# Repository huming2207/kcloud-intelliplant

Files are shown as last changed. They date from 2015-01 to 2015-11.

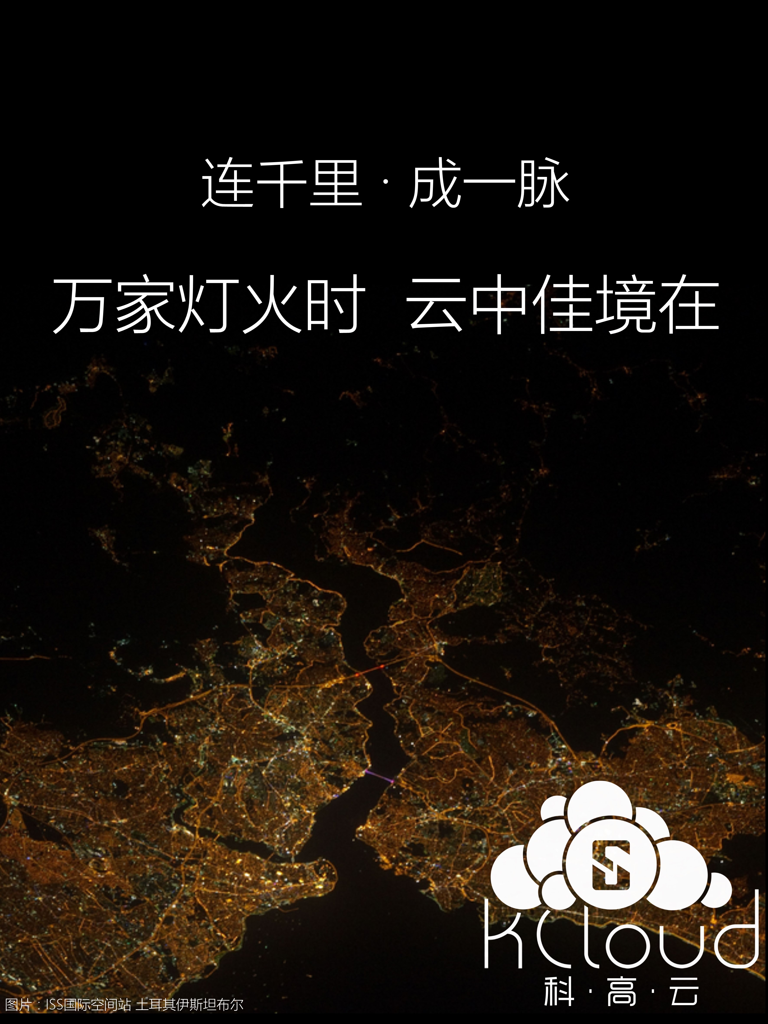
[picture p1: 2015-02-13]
RaspiController/PC Client/KCloud IntelliPlant for Windows/Resources/3月海报2.jpg

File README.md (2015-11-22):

# HuStudio IntelliPlant
One of the sub-projects of Shenzhen Highschool of Science former "KCloud" private cloud service project.

=========
Overview
=========
The IntelliPlant project is one of the sub-projects of Shenzhen High School of Science KCloud. 

It's an Arduino based open source crop auto-managing system.

The project mainly maintained by Jackson Ming Hu in KGTCU, Techonology Clubs Union of Shenzhen High School of Science.

It has two parts, one is the master (controller) side, the other is slave (arduino nodes) side. The node is an Arduino Uno/ProMini/Mega or Raspberry Pi.

The node has a temperature & humidity sensor , an air pressure sensor and an air quality sensor and it controls the pump with a relay and it will automatically calculate the water capacity by the weather condition.

The controller can get the node's data by wireless UART serial port and then display the data on its screen and upload the data to Yeelink Cloud Platform.

=========
Development Environment Requirements 
=========

1. The PC client must use Virtual Studio version newer than 2012 or 2013, otherwise it will reports many strange mistakes.

2. Recommended development environment:

		--> Arduino IDE 1.60 for arduino node
		
		--> Virtual Studio 2013r3
		
		--> Debian 7.x or OpenWrt 14.04 "Barrier Breaker" for Raspberry Pi with Python 2.7   

=========
About this project
=========

Project author: IT Club, Technical Club Union of Shenzhen Highschool of Science

Project administrator: Jackson Ming Hu <huming2207@gmail.com>

Arduino software development: Jackson Ming Hu

PC Client development & advising: Jackson Ming Hu, Junhao Liang

Shield design: Yichuan Lee

This project is a open source project and all the source code are protected by GPLv2 licence.

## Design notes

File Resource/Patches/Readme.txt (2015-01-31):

HardwareSerial.cpp:

The arduino original hardware serial library's transfer buffer is too small, so I've changed the SERIAL_BUFFER_SIZE (originally definition is 64 bit) to 256bit for ATMEGA8U2/ATMEGA*28P/ATMEGA16U2 and 512bit for Atmega 2560 in case  of the data loss.

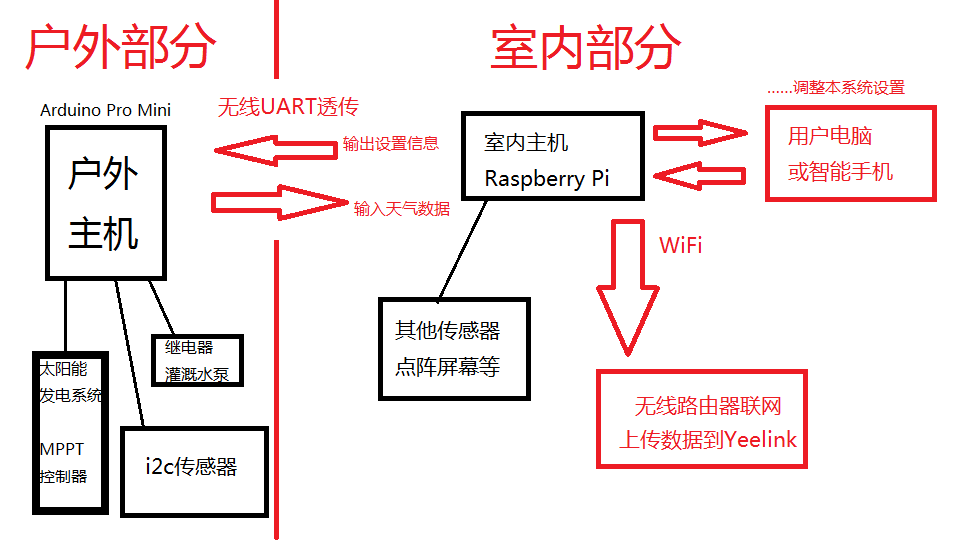
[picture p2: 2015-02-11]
Resource/mind-map-1.png

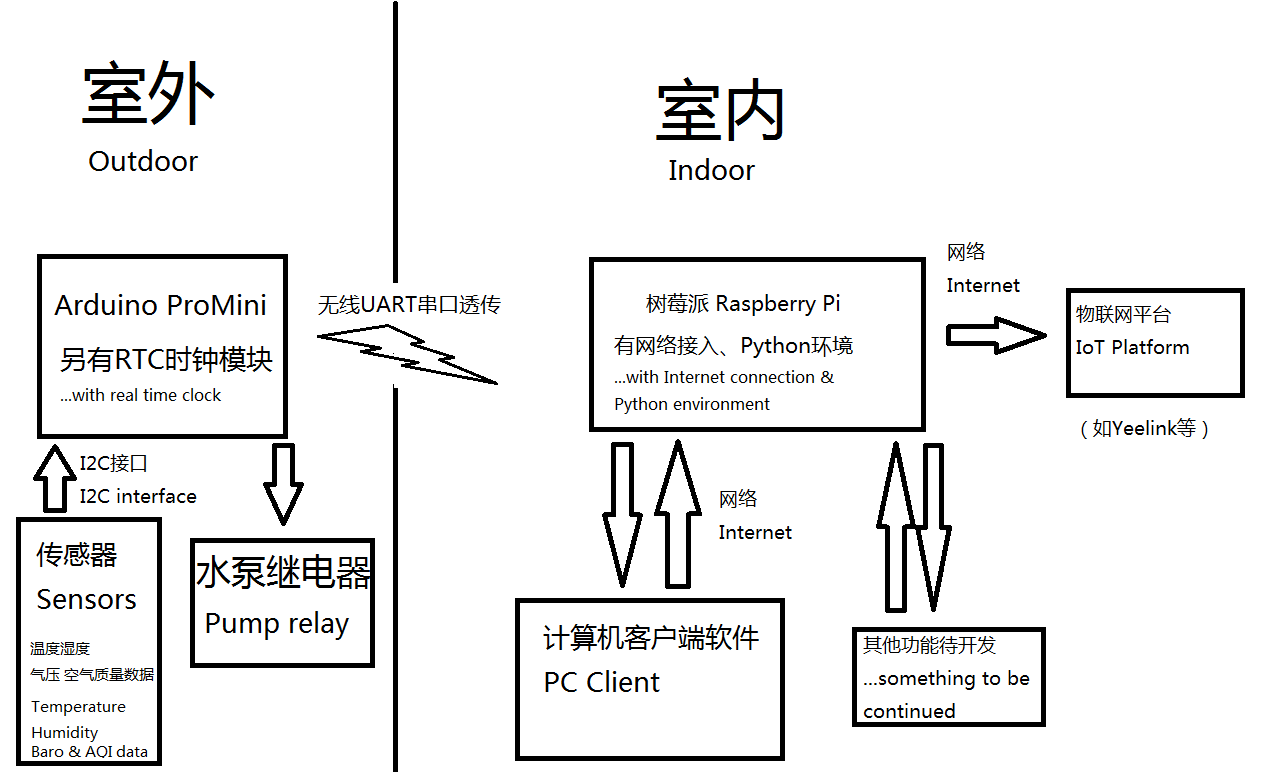
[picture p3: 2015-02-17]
Resource/mind-map-final.png

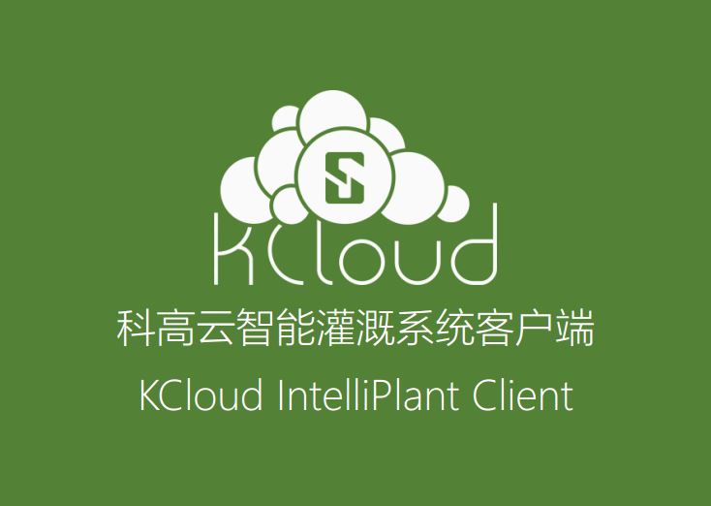
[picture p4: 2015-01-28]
Resource/mainstart.JPG

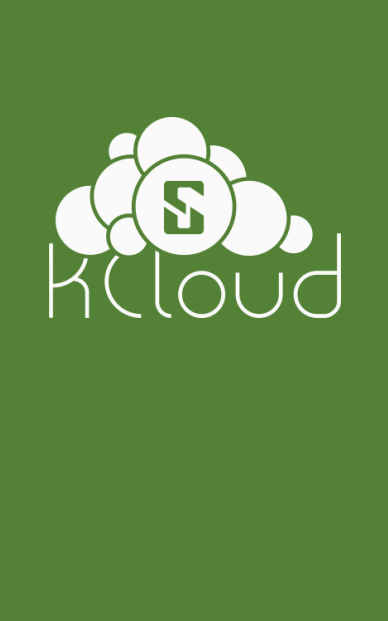
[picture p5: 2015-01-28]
Resource/about.PNG

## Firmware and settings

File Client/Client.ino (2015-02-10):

#include <Wire.h>
#include <LiquidCrystal_I2C.h>
#include <uartWIFI.h>
#include <avr/eeprom.h>
#define EEPROM_write(address, var) eeprom_write_block((const void *)&(var), (void *)(address), sizeof(var))
#define EEPROM_read(address, var) eeprom_read_block((void *)&(var), (const void *)(address), sizeof(var)) 

String WifiSSID;                
String WifiPassword;    
String SerialIn;
String YeelinkID1;
String YeelinkSensor1;
String YeelinkSensor2;
String YeelinkSensor3;
String YeelinkSensor4;
String YeelinkSensor5;
String YeelinkDeviceID;
float SerialNumData[9] = {0};

unsigned long lastConnectionTime = 0;          // last time you connected to the server, in milliseconds
boolean lastConnected = false;                 // state of the connection last time through the main loop
const unsigned long postingInterval = 5*1000; 
String returnValue = ""; 
boolean ResponseBegin = false;

/* Wifi Status. 
*/
int WifiStatus = 0;

LiquidCrystal_I2C lcd(0x27,20,4);  
WIFI wifi;
char YeelinkServer[] = "api.yeelink.net";


void setup()
{
  lcd.init();                      // Initialize the lcd 
  lcd.init();
  lcd.backlight();
  EEPROM_read(1000,WifiSSID);   // Read the Wifi SSID
  EEPROM_read(1500,WifiPassword); // Read the Wifi Password
  EEPROM_read(2000,YeelinkID1);
  EEPROM_read(300,YeelinkSensor1);
  EEPROM_read(400,YeelinkSensor2);
  EEPROM_read(500,YeelinkSensor3);
  EEPROM_read(600,YeelinkSensor4);
  EEPROM_read(700,YeelinkSensor5);
  EEPROM_read(800,YeelinkDeviceID);
  DebugSerial.println("SHSS KGTCU IntelliPlant Client");
  DebugSerial.println("Now initalized.");
  wifi.begin();
  bool b = wifi.Initialize(STA, WifiSSID, WifiPassword);
  if(!b)
  {
    DebugSerial.println("...Wifi hasn't connected successfully.");
      lcd.clear();
      lcd.setCursor(3,0);
      lcd.print("Hello, world!");
      lcd.setCursor(1,1);
      lcd.print("KCloud IntelliPlant");
      lcd.setCursor(0,2);
      lcd.print("WIFI CONNECTION FAIL");
      delay(10000);
      WifiStatus = -1;
  }
  delay(10000);
  lcd.setCursor(3,0);
  lcd.print("Hello, world!");
  lcd.setCursor(2,1);
  lcd.print("KCloud IntelliPlant");
  lcd.setCursor(0,2);
  lcd.print("IP:");
  lcd.print(wifi.showIP());
  lcd.setCursor(3,3);
  lcd.print("WIFI CONNECTED!!");
  delay(5000);
  WifiStatus = 1;
}


void loop()
{
    int j = 0;
    while (Serial.available() > 0)  
    {
        SerialIn += char(Serial.read());
        delay(2);
    }
    if (SerialIn.length() > 0)
    {
      if(SerialIn[0] == 'Y' || SerialIn[0] == 'F' || SerialIn[0] == 'A' || SerialIn[0] == 'B' || SerialIn[0] == 'C' || SerialIn[0] == 'D' || SerialIn[0] == 'E' || SerialIn[0] == 'W' ||  SerialIn[0] == 'R')
      {
       YeelinkDeviceIDSave();
       YeelinkIDSave();
       YeelinkSensorSave1();
       YeelinkSensorSave2();
       YeelinkSensorSave3();
       YeelinkSensorSave4();
       YeelinkSensorSave5();
       WifiPasswordSave();
       WifiSSIDSave();
      }
      else
      {
          for(unsigned int i = 0; i < SerialIn.length() ; i++)
          {
            if(SerialIn[i] == ',')
            {
               j++; //If meets a comma then j+1 and jump to the next setting data.
            }
            else
            {
               SerialNumData[j] = SerialNumData[j] * 10 + (SerialIn[i] - '0');
            }
          }

        SerialIn = String("");  // Clear up all the old SerialIn data.
        /* *******************************************************************************
           The "SerialNumData[0]" lets the server decide which setting should be changed. 
           1 = Normal weather data.
           2 = Schedule data.
          ******************************************************************************** */ 
        switch (int(SerialNumData[0])) {  
        case 1:
          YeeLinkSendSensorData();
          break;
        case 2:
          LCDShowSchedule();
          break;
        default: 
          break;
        }
        
        for(int i = 0; i < 10; i++)
        {
   	    SerialNumData[i] = 0;
        }
      }
    }
    LCDClearWithoutBlink();
    lcd.setCursor(3,0);
    lcd.print("Status:");
    switch (WifiStatus){
    case -1:
      lcd.print("NO WIFI");
      break;
    case 0:
      lcd.print("UNKNOWN");
      break;
    case 1:
      lcd.print("CONNECTED");
      break;
    case 2:
      lcd.print("NO INTERNET");
      break;
    default:
      break;
    }
    

    

}

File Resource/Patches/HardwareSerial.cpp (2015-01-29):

/*
  HardwareSerial.cpp - Hardware serial library for Wiring
  Copyright (c) 2006 Nicholas Zambetti.  All right reserved.

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
  Modified 23 November 2006 by David A. Mellis
  Modified 28 September 2010 by Mark Sproul
  Modified 14 August 2012 by Alarus
*/

#include <stdlib.h>
#include <stdio.h>
#include <string.h>
#include <inttypes.h>
#include "Arduino.h"
#include "wiring_private.h"

// this next line disables the entire HardwareSerial.cpp, 
// this is so I can support Attiny series and any other chip without a uart
#if defined(UBRRH) || defined(UBRR0H) || defined(UBRR1H) || defined(UBRR2H) || defined(UBRR3H)

#include "HardwareSerial.h"

/*
 * on ATmega8, the uart and its bits are not numbered, so there is no "TXC0"
 * definition.
 */
#if !defined(TXC0)
#if defined(TXC)
#define TXC0 TXC
#elif defined(TXC1)
// Some devices have uart1 but no uart0
#define TXC0 TXC1
#else
#error TXC0 not definable in HardwareSerial.h
#endif
#endif

// Define constants and variables for buffering incoming serial data.  We're
// using a ring buffer (I think), in which head is the index of the location
// to which to write the next incoming character and tail is the index of the
// location from which to read.
#if (RAMEND <= 1000)
	 #define SERIAL_BUFFER_SIZE 64
#else
#if (RAMEND <= 2000)
	 #define SERIAL_BUFFER_SIZE 256
#else
	 #define SERIAL_BUFFER_SIZE 512
#endif
#endif

struct ring_buffer
{
  unsigned char buffer[SERIAL_BUFFER_SIZE];
  volatile unsigned int head;
  volatile unsigned int tail;
};

#if defined(USBCON)
  ring_buffer rx_buffer = { { 0 }, 0, 0};
  ring_buffer tx_buffer = { { 0 }, 0, 0};
#endif
#if defined(UBRRH) || defined(UBRR0H)
  ring_buffer rx_buffer  =  { { 0 }, 0, 0 };
  ring_buffer tx_buffer  =  { { 0 }, 0, 0 };
#endif
#if defined(UBRR1H)
  ring_buffer rx_buffer1  =  { { 0 }, 0, 0 };
  ring_buffer tx_buffer1  =  { { 0 }, 0, 0 };
#endif
#if defined(UBRR2H)
  ring_buffer rx_buffer2  =  { { 0 }, 0, 0 };
  ring_buffer tx_buffer2  =  { { 0 }, 0, 0 };
#endif
#if defined(UBRR3H)
  ring_buffer rx_buffer3  =  { { 0 }, 0, 0 };
  ring_buffer tx_buffer3  =  { { 0 }, 0, 0 };
#endif

inline void store_char(unsigned char c, ring_buffer *buffer)
{
  int i = (unsigned int)(buffer->head + 1) % SERIAL_BUFFER_SIZE;

  // if we should be storing the received character into the location
  // just before the tail (meaning that the head would advance to the
  // current location of the tail), we're about to overflow the buffer
  // and so we don't write the character or advance the head.
  if (i != buffer->tail) {
    buffer->buffer[buffer->head] = c;
    buffer->head = i;
  }
}

#if !defined(USART0_RX_vect) && defined(USART1_RX_vect)
// do nothing - on the 32u4 the first USART is USART1
#else
#if !defined(USART_RX_vect) && !defined(USART0_RX_vect) && \
    !defined(USART_RXC_vect)
  #error "Don't know what the Data Received vector is called for the first UART"
#else
  void serialEvent() __attribute__((weak));
  void serialEvent() {}
  #define serialEvent_implemented
#if defined(USART_RX_vect)
  ISR(USART_RX_vect)
#elif defined(USART0_RX_vect)
  ISR(USART0_RX_vect)
#elif defined(USART_RXC_vect)
  ISR(USART_RXC_vect) // ATmega8
#endif
  {
  #if defined(UDR0)
    if (bit_is_clear(UCSR0A, UPE0)) {
      unsigned char c = UDR0;
      store_char(c, &rx_buffer);
    } else {
      unsigned char c = UDR0;
    };
  #elif defined(UDR)
    if (bit_is_clear(UCSRA, PE)) {
      unsigned char c = UDR;
      store_char(c, &rx_buffer);
    } else {
      unsigned char c = UDR;
    };
  #else
    #error UDR not defined
  #endif
  }
#endif
#endif

#if defined(USART1_RX_vect)
  void serialEvent1() __attribute__((weak));
  void serialEvent1() {}
  #define serialEvent1_implemented
  ISR(USART1_RX_vect)
  {
    if (bit_is_clear(UCSR1A, UPE1)) {
      unsigned char c = UDR1;
      store_char(c, &rx_buffer1);
    } else {
      unsigned char c = UDR1;
    };
  }
#endif

#if defined(USART2_RX_vect) && defined(UDR2)
  void serialEvent2() __attribute__((weak));
  void serialEvent2() {}
  #define serialEvent2_implemented
  ISR(USART2_RX_vect)
  {
    if (bit_is_clear(UCSR2A, UPE2)) {
      unsigned char c = UDR2;
      store_char(c, &rx_buffer2);
    } else {
      unsigned char c = UDR2;
    };
  }
#endif

#if defined(USART3_RX_vect) && defined(UDR3)
  void serialEvent3() __attribute__((weak));
  void serialEvent3() {}
  #define serialEvent3_implemented
  ISR(USART3_RX_vect)
  {
    if (bit_is_clear(UCSR3A, UPE3)) {
      unsigned char c = UDR3;
      store_char(c, &rx_buffer3);
    } else {
      unsigned char c = UDR3;
    };
  }
#endif

void serialEventRun(void)
{
#ifdef serialEvent_implemented
  if (Serial.available()) serialEvent();
#endif
#ifdef serialEvent1_implemented
  if (Serial1.available()) serialEvent1();
#endif
#ifdef serialEvent2_implemented
  if (Serial2.available()) serialEvent2();
#endif
#ifdef serialEvent3_implemented
  if (Serial3.available()) serialEvent3();
#endif
}
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

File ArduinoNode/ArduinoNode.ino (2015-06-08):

#include <AM2321.h>
#include <EEPROM.h>
#include <Wire.h>
#include <DS3231RTC.h>



 /* BMP180/BMP085 barometer statements and settings */
#define BMP085_ADDRESS 0x77 
float temperature;
float pressure;

const unsigned char OSS = 0; 
int ac1;
int ac2;
int ac3;
unsigned int ac4;
unsigned int ac5;
unsigned int ac6;
int b1;
int b2;
int mb;
int mc;
int md;
long b5; 

/* Dallas (Maxim) DS3231 RTC Clock statements and settings */
DS3231RTC RTC;
Time t;

/* DHT33 (aka. AM232x) statements */
AM2321 DHT;

/* MQ135 toxic gas sensor */
float GasPPM;
float GasAlg;

/* Serial input statements */
String SerialIn;
float SerialNumData[9] = {0};

/* Relay control pin on D7 */
int RelayControl = 8;

/* Declare some schedule integers */
int ScheduleHr;
int ScheduleMin;
int ScheduleSec;
unsigned long ScheduleCapacity;
int ScheduleStatus;
int ScheduleNum;
int Sec1;
int Min1;
int Hr1;
int Ratio;
long XWeatherOut;
unsigned long YWeatherOut;
int AutoSwitch;
int MainSwitch = 0;

/* SolarMonitor statements */
int SolarVoltageAnalog = 0; // The solar voltage analog data from Analog Pin 0 (A0)
int SolarCurrentAnalog = 1; // The solar current analog data from Analog Pin 1 (A1)
float SolarVoltage;
float SolarCurrent;


void setup(){
      digitalWrite(7, HIGH);
      pinMode(7, OUTPUT);
      Serial.begin(9600);
      pinMode(RelayControl,OUTPUT);
      digitalWrite(RelayControl,LOW);
      bmp085Calibration();
      t = RTC.getTime();
}




void loop(){
      GasAlg = float(analogRead(A3));
      GasPPM = (GasAlg / 1023.00) * float(InputVcc()) * 0.25;
      pressure = bmp085GetPressure(bmp085ReadUP());
       
        /* Simplify the code in main Server.ino */
       SerialDataRead();  // Read the serial data first. :-)
       SerialWeatherOutput();
        
        /* Check if the time meets the schedule */
       RelaySchedule1();
       RelaySchedule2();
       RelaySchedule3();
       
       SolarVoltageCalculate();
       SolarCurrentCalculate();
       
}

void BoardReset(){
  /* 
      Use a very short watchdog loop to force reset the arduino
      See also: http://www.atmel.com/images/Atmel-8271-8-bit-AVR-Microcontroller-ATmega48A-48PA-88A-88PA-168A-168PA-328-328P_datasheet_Complete.pdf
                http://playground.arduino.cc/Main/ArduinoReset
       But, unfortunately some Chinese Arduino ProMini clones (including mine)  have some issues on bootloader, so if we use the AVR internal watchdog, it would get stuck when reboot
       See also :http://arduino.stackexchange.com/questions/2922/watchdog-timer-stuck-in-restart-loop-green-led-flashing
       
  
  */
  
  /* 
      Here, we need to connect a wire between pin D7 and pin DTR (reset)
      According to my experiments, a pull-up resistor is unnecessary.
  */    
  digitalWrite(7, LOW);

}

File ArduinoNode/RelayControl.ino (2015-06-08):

/* 
    SHSS KCloud IntelliPlant Node source code
    Author: Jackson Ming Hu <huming2207@gmail.com>
            Technical Club Union of Shenzhen Highschool of Science
            ...and some unknown guys including the TAOBAO retailers, thanks them!!
			深圳科学高中 科高云子项目 智慧农业物联网灌溉机
			深圳科学高中技术类社团联合会自动化电子项目组
			程序作者：胡铭 huming2207@gmail.com
			
    ***THIS CODE IS PROTECTED BY LGPL LICENCE, FOR NON-COMMERCIAL USE ONLY! ***
        本程序受LGPL协议保护，严禁商用。
     
     RelayControl.ino -->   Relay timing controller 
                            
                       
*/

void CalculateWeather(){
  /* 
     This is a testing formula of the "Weather2WaterCapacity" part.
     It's too humble, but I will keep working on it. ----Jackson @ Jan 30 2015
     
     Some requirements:
     1. The pump must work longer than 10 seconds per schedule and less than 60 seconds per schedule.
     2. ... (To be continued. I will ask my mum and grandma some advices, who is expert in agriculture.)
   */
  DHT.read();
  Ratio = int(EEPROM.read(20));
  XWeatherOut = (int((DHT.humidity/2)) - int((DHT.temperature/1.5)) - int((pressure/5000)));
  YWeatherOut = -XWeatherOut + 60 + Ratio;
  if (YWeatherOut > 60){
    YWeatherOut = 60; // Force the output shorter than 60.
  }
  if (YWeatherOut < 10){
    YWeatherOut = 10; // Force the output longer than 60.
  }
}


/* 
     BEGIN PUMP RELAY SCHEDULE PARTS 
     
     Feb 11 2015: I have no choice but to use delay(), since it is the easiest and the most stable way to control the interruption of the pump without Time library.
     
*/

void RelaySchedule1(){
  t = RTC.getTime();
  ScheduleHr = int(EEPROM.read(1));
  ScheduleMin = int(EEPROM.read(2));
  ScheduleSec = int(EEPROM.read(3));
  ScheduleCapacity = int(EEPROM.read(4));
  MainSwitch = int(EEPROM.read(5));
  AutoSwitch = int(EEPROM.read(6));
  
  
  if (MainSwitch == 1 && ScheduleHr == t.hour() && ScheduleMin == t.minute() && ScheduleSec == t.second())
  {
    digitalWrite(RelayControl, HIGH);
    if (AutoSwitch == 1)
    {
        SerialScheduleOutput();
        delay(YWeatherOut * 1000L);
        digitalWrite(RelayControl,LOW);
        //BoardReset();
    }
    else
    {
        SerialScheduleOutput();
        delay(ScheduleCapacity * 1000L);
        digitalWrite(RelayControl,LOW);
        //BoardReset();
    }
  }
}


void RelaySchedule2(){
  t = RTC.getTime();
  ScheduleHr = int(EEPROM.read(7));
  ScheduleMin = int(EEPROM.read(8));
  ScheduleSec = int(EEPROM.read(9));
  ScheduleCapacity = int(EEPROM.read(10));
  MainSwitch = int(EEPROM.read(11));
  AutoSwitch = int(EEPROM.read(12));
  
  
  if (MainSwitch == 1 && ScheduleHr == t.hour() && ScheduleMin == t.minute() && ScheduleSec == t.second())
  {
    digitalWrite(RelayControl, HIGH);
    if (AutoSwitch == 1)
    {
        SerialScheduleOutput();
        delay(YWeatherOut * 1000L);
        digitalWrite(RelayControl,LOW);
        //BoardReset();
    }
    else
    {
        SerialScheduleOutput();
        delay(ScheduleCapacity * 1000L);
        digitalWrite(RelayControl,LOW);
        //BoardReset();
    }
  }
}

void RelaySchedule3(){
  t = RTC.getTime();
  ScheduleHr = int(EEPROM.read(13));
  ScheduleMin = int(EEPROM.read(14));
  ScheduleSec = int(EEPROM.read(15));
  ScheduleCapacity = int(EEPROM.read(16));
  MainSwitch = int(EEPROM.read(17));
  AutoSwitch = int(EEPROM.read(18));
  
  
  if (MainSwitch == 1 && ScheduleHr == t.hour() && ScheduleMin == t.minute() && ScheduleSec == t.second())
  {
    digitalWrite(RelayControl, HIGH);
    if (AutoSwitch == 1)
    {
        SerialScheduleOutput();
        delay(YWeatherOut * 1000L);
        digitalWrite(RelayControl,LOW);
        //BoardReset();
    }
    else
    {
        SerialScheduleOutput();
        delay(ScheduleCapacity * 1000);
        digitalWrite(RelayControl,LOW);
        //BoardReset();
    }
  }
}




void EEPROMDebug(){
  ScheduleHr = int(EEPROM.read(1));
  ScheduleMin = int(EEPROM.read(2));
  ScheduleSec = int(EEPROM.read(3));
  ScheduleCapacity = int(EEPROM.read(4));
  MainSwitch = int(EEPROM.read(5));
  AutoSwitch = int(EEPROM.read(6));
  Serial.println("** DEBUG: EEPROM - SCHEDULE");
  Serial.print("** ");
  Serial.print(ScheduleHr);
  Serial.print("  ");
  Serial.print(ScheduleMin);
  Serial.print("  ");
  Serial.print(ScheduleSec);
  Serial.print("  ");
  Serial.print(ScheduleCapacity);
  Serial.print("  ");
  Serial.println(MainSwitch);
}  

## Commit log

2015-01-28 Redesigned a new type of serial protocol
    Redesigned a new type of serial protocol between server and client.
    [Settings.ino]
2015-01-28 Add 3rd library -- IIC LCD Control
    [diff.txt]
2015-01-28 Add saving settings section for Client & fix bugs
    Add saving settings section for Client & fix bugs
    [Client.ino, Settings.ino]
2015-01-28 Update UI design for PC client
    Just a UI design, I'm still working for the arduino.
2015-01-29 Add arduino HardwareSerial patch
2015-01-29 Found a small mistake
    [Client.ino]
2015-01-31 修正一些意识形态问题
2015-02-01 Several changes to Server
    1. Change the AM2301 (DHT21) sensor to AM2321, since it is not stable
    and often cause strange crashes.
    2. Remove adafruit BOSCH barometer library and ported the MMWCGND BOSCH
    barometer library to optmize and reduce the whole firmware's size.
    [Barometer.ino, RelayControl.ino, SerialOutput.ino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]
2015-02-04 Update Server and PC client software
    My AM2321 (aka. DHT3x) has arrived and now all the staffs restarted. I
    hope I can finish them before Chinese Spring festival~!
2015-02-06 Change SHARP dust sensor to DSM501A sensor
    After received and tested the SHARP sensor, I've found the sensor is
    extremely unstable. Maybe the digital signal from arduino is not right
    or... for some reason the signal itself is not stable enough. So I
    bought a korean-made DSM501A sensor and use the offical library from
    TAOBAO retailer to refine the program.
    [diff.txt]
2015-02-06 Refine the path
    [diff.txt]
2015-02-08 Continue...
    1. ...to add the SolarMonitor.ino code.
    2. ...fix a unused variables warnings from DM501 library.
    [SolarMonitor.ino]
2015-02-09 MANY CHANGES!!!
    1. Give up using DS323x RTC since it often causes some strange problem,
    like revert the time to Jan/1/1970. I don't know why, maybe my hardware
    modules have some issues. I will add some functions to sync the time
    from NTP servers by using the slave side.
    2. Fix and delete the DSM501 library. It is obsoleted and may cause
    crashes like no any output from the serial port.
    [RelayControl.ino, SerialInput.ino, SerialOutput.ino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]
2015-02-10 Revert DS323x
    I've found the problem which was caused by the arduino board's internal
    hardware clock and then replaced it with a new arduino promini board.
    Now the RTC problem is solved
    [RelayControl.ino, SerialOutput.ino, Settings.ino]
2015-02-10 Found a bloody mistake on EEPROM
    now fixed
    [Client.ino, RelayControl.ino, Settings.ino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]
2015-02-11 Dust sensor concerntration fix
    [RelayControl.ino, SerialOutput.ino]
2015-02-11 Daily work done
    1. Give up using AVR EEPROM R/W because it seems doesn't work in Arduino
    SDK 1.60
    2. Realy control changes
    [RelayControl.ino, SerialInput.ino, Settings.ino]
2015-02-12 Fix missing t.second() judgement
    [RelayControl.ino]
2015-02-12 Now testing the Yeelink client on Raspberry Pi
2015-02-13 Prepare to redesign the Windows PC Client
    [Client.ino, IICLCD.ino, Settings.ino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]
2015-02-13 Let the Raspberry side understand the configuration
2015-02-14 Cancel the dust sensor since it use too much CPU
    [SerialInput.ino, SerialOutput.ino, SolarMonitor.ino]
2015-02-14 add support for arduino setting
2015-02-16 Fix bugs and prepare for the stable release
    [RelayControl.ino, SerialInput.ino, yeelink.py]
2015-02-17 Some changes
    1. Fix reboot loop issue caused by the watchdog bugs in ArduinoProMini
    2. Re-named the files
    [Barometer.ino, Client.ino, HardwareSerial.cpp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]
2015-02-19 Lunar new year changes
    1. Small fix.
    2. Add Chinese comments in Arduino source code.
    [ArduinoNode.ino, Barometer.ino, RelayControl.ino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]
2015-02-19 Reset GBK to UTF8
    [ArduinoNode.ino]
2015-02-23 Some new things
    1. Initial Intelliplant hardware (Arduino pro mini extention board) PCB
    design, using Sprint Layout 6.0
    2. ArduinoNode: Add a filter algorithm for barometer.
    [intelliplant-1.drl, intelliplant-1_底层丝印层.gbr, intelliplant-1_底层敷铜层.gbr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]
2015-06-04 NativeControl: Init
    一个新的本地调试工具，不必从Python服务端周转数据，更加方便
